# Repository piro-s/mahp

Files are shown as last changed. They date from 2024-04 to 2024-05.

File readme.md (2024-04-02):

# Music mini-amplifier with indicator:  
A simple two-channel amplifier on a chip TDA2822 with indicator.  

### Schemes:  
###### Amplifier_v0.1:  
[pdf](amplifier/docs/mahp_v0.1.pdf)  
###### Indicator_v0.1:  
[pdf](indicator/docs/indicator_v0.1.pdf)  

### Images:  
###### Amplifier_v0.1:  
top:  
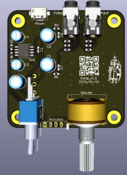
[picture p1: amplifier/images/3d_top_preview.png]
mahp_top_v0.1
  
bottom:  
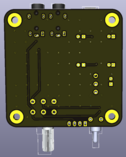
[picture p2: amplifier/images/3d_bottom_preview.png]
mahp_bottom_v0.1
  

###### Indicator_v0.1:  
top:  
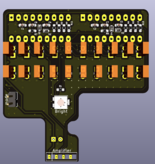
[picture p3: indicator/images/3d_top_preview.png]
indicator_top_v0.1
  
bottom:  
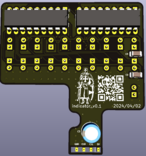
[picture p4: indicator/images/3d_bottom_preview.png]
indicator_bottom_v0.1
  

###### gerber:  
Archive for production:  
[Amplifier_v0.1](https://github.com/piro-s/mahp/raw/master/amplifier/gerber/mahp_v0.1.zip)  
[Indicator_v0.1](https://github.com/piro-s/mahp/raw/master/indicator/gerber/indicator_v0.1.zip)

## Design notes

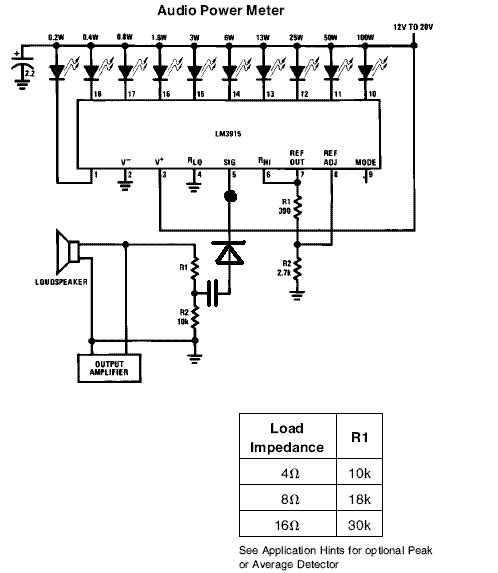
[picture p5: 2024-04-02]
indicator/datashits/lm3915.GIF

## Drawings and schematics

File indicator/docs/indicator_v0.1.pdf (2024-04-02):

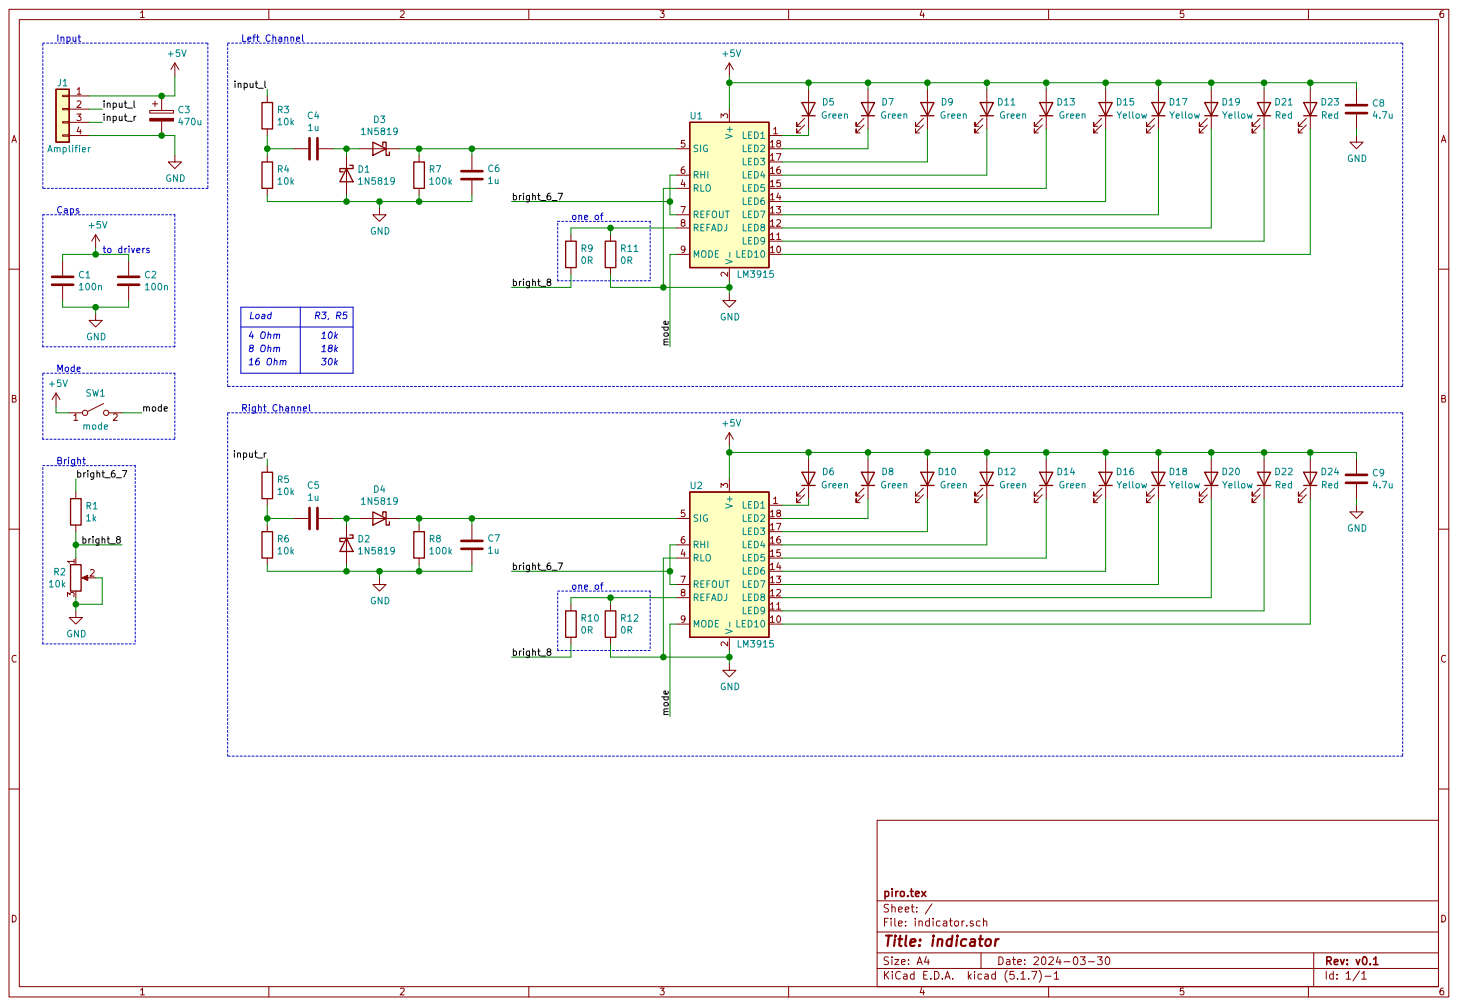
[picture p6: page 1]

3 RLO 4 SIG 5 RHI 6 REFOUT 7 REFADJ 8 MODE 9 U1

bright_6_7
one of

8 Ohm

3 RLO 4 SIG 5 RHI 6 REFOUT 7 REFADJ 8 MODE 9 U2

Id: 1/1 Title: indicator File: indicator.sch Sheet: / piro.tex

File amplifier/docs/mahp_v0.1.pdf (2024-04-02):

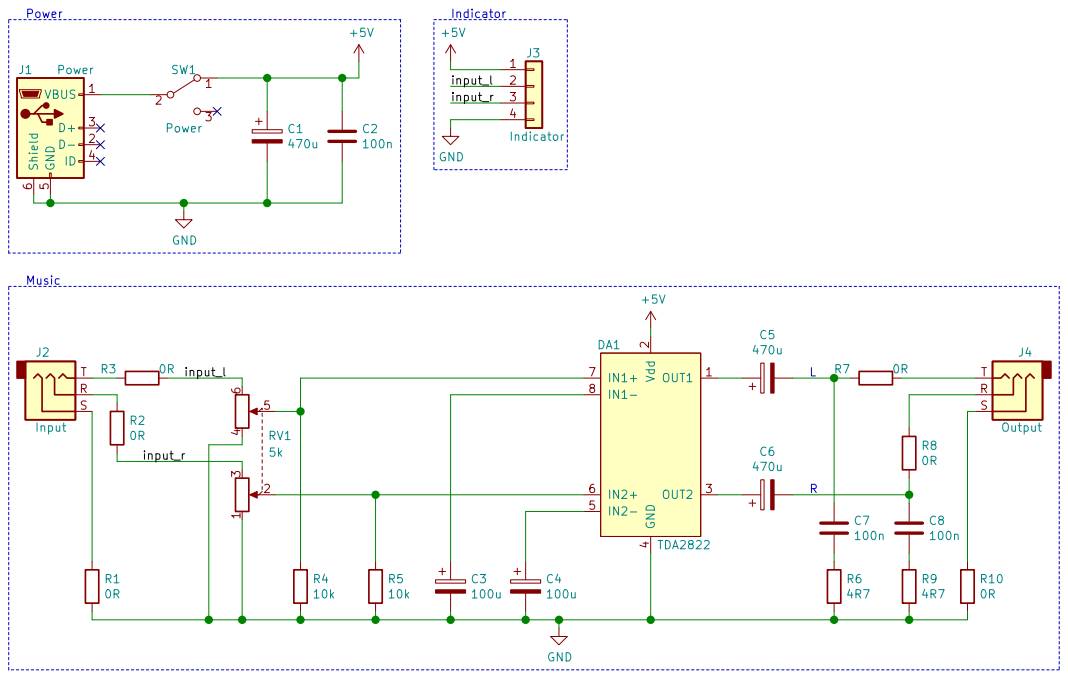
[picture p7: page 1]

File: music_amplifier_headphones.sch Sheet: / piro.tex

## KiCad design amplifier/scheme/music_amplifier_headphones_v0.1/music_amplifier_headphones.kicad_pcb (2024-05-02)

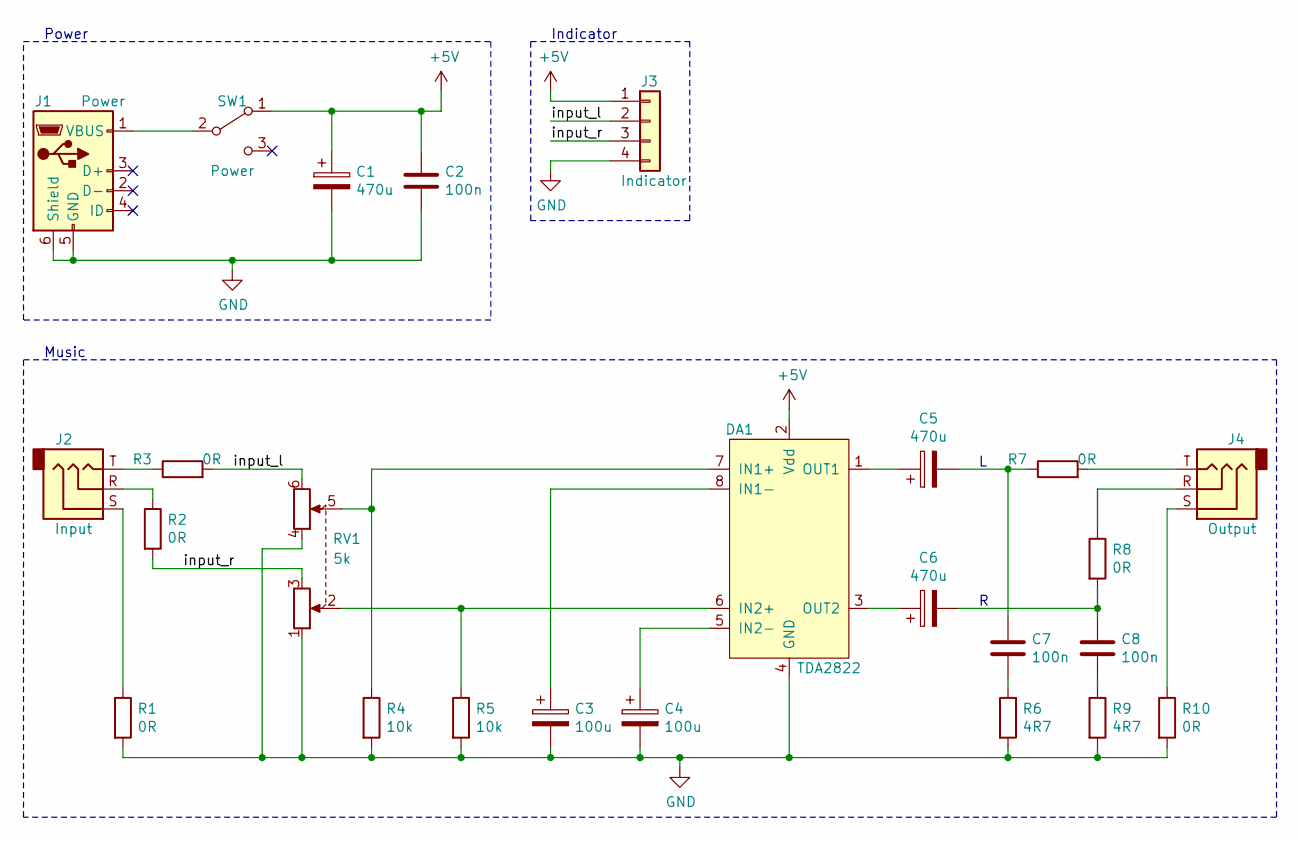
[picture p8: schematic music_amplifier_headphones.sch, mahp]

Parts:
C1, C5, C6: 470u; CP_Radial_D6.3mm_P2.50mm
C2, C7, C8: 100n; C_0603_1608Metric_Pad1.08x0.95mm_HandSolder
C3, C4: 100u; CP_Radial_D5.0mm_P2.00mm
DA1: TDA2822; SO-8_5.3x6.2mm_P1.27mm
J1: Power; USB_Micro-B_Amphenol_10104110_Horizontal
J2: Input; Jack_3.5mm_PJ322
J3: Indicator; Indicator_LM3915_female
J4: Output; Jack_3.5mm_PJ322
R1, R2, R3, R7, R8, R10: 0R; R_0603_1608Metric_Pad0.98x0.95mm_HandSolder
R4, R5: 10k; R_0603_1608Metric_Pad0.98x0.95mm_HandSolder
R6, R9: 4R7; R_0603_1608Metric_Pad0.98x0.95mm_HandSolder
RV1: 5k; Potentiometer_Alps_RK163_Dual_Horizontal
SW1: Power; MTS-102-C4

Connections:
+5V: C1.1, C2.1, DA1.2 (Vdd), J3.1, SW1.1 (A)
/input_l: J3.2, R3.2, RV1.6
/input_r: J3.3, R2.2, RV1.3
GND: C1.2, C2.2, C3.2, C4.2, DA1.4 (GND), J1.5 (GND), J1.6 (Shield), J3.4, R1.2, R4.2, R5.2, R6.2, R9.2, R10.2, RV1.1, RV1.4
unnamed: C3.1, DA1.8 (IN1-)
unnamed: C4.1, DA1.5 (IN2-)
unnamed: C5.1, DA1.1 (OUT1)
unnamed: C5.2, C7.1, R7.1
unnamed: C6.1, DA1.3 (OUT2)
unnamed: C6.2, C8.1, R8.2
unnamed: C7.2, R6.1
unnamed: C8.2, R9.1
unnamed: DA1.6 (IN2+), R5.1, RV1.2
unnamed: DA1.7 (IN1+), R4.1, RV1.5
unnamed: J1.1 (VBUS), SW1.2 (B)
unnamed: J2.R, R2.1
unnamed: J2.S, R1.1
unnamed: J2.T, R3.1
unnamed: J4.R, R8.1
unnamed: J4.S, R10.1
unnamed: J4.T, R7.2

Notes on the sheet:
Music
Power
Indicator

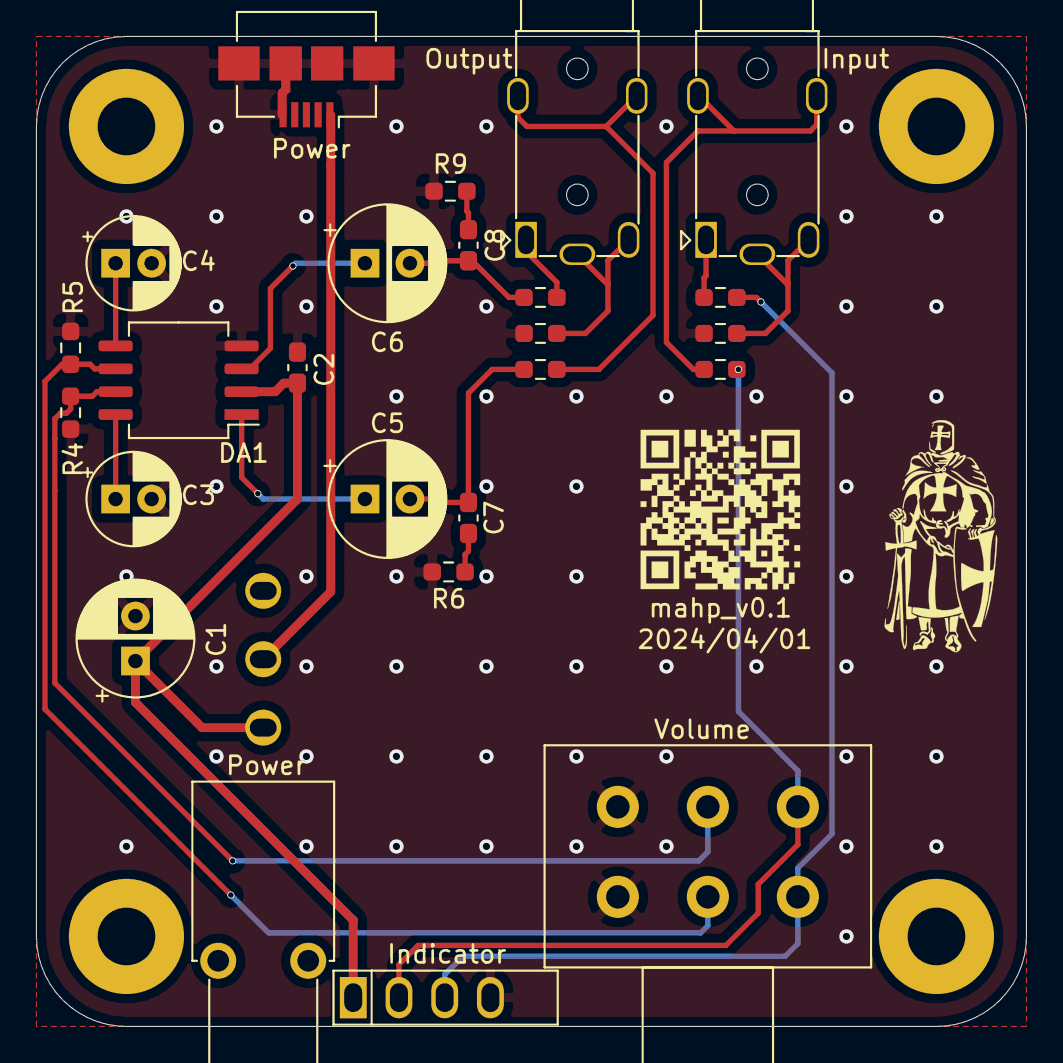
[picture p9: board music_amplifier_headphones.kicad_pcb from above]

Board: 2 copper layers, 55.0 x 55.0 mm, 25 parts (0 on the bottom side), 21 nets.

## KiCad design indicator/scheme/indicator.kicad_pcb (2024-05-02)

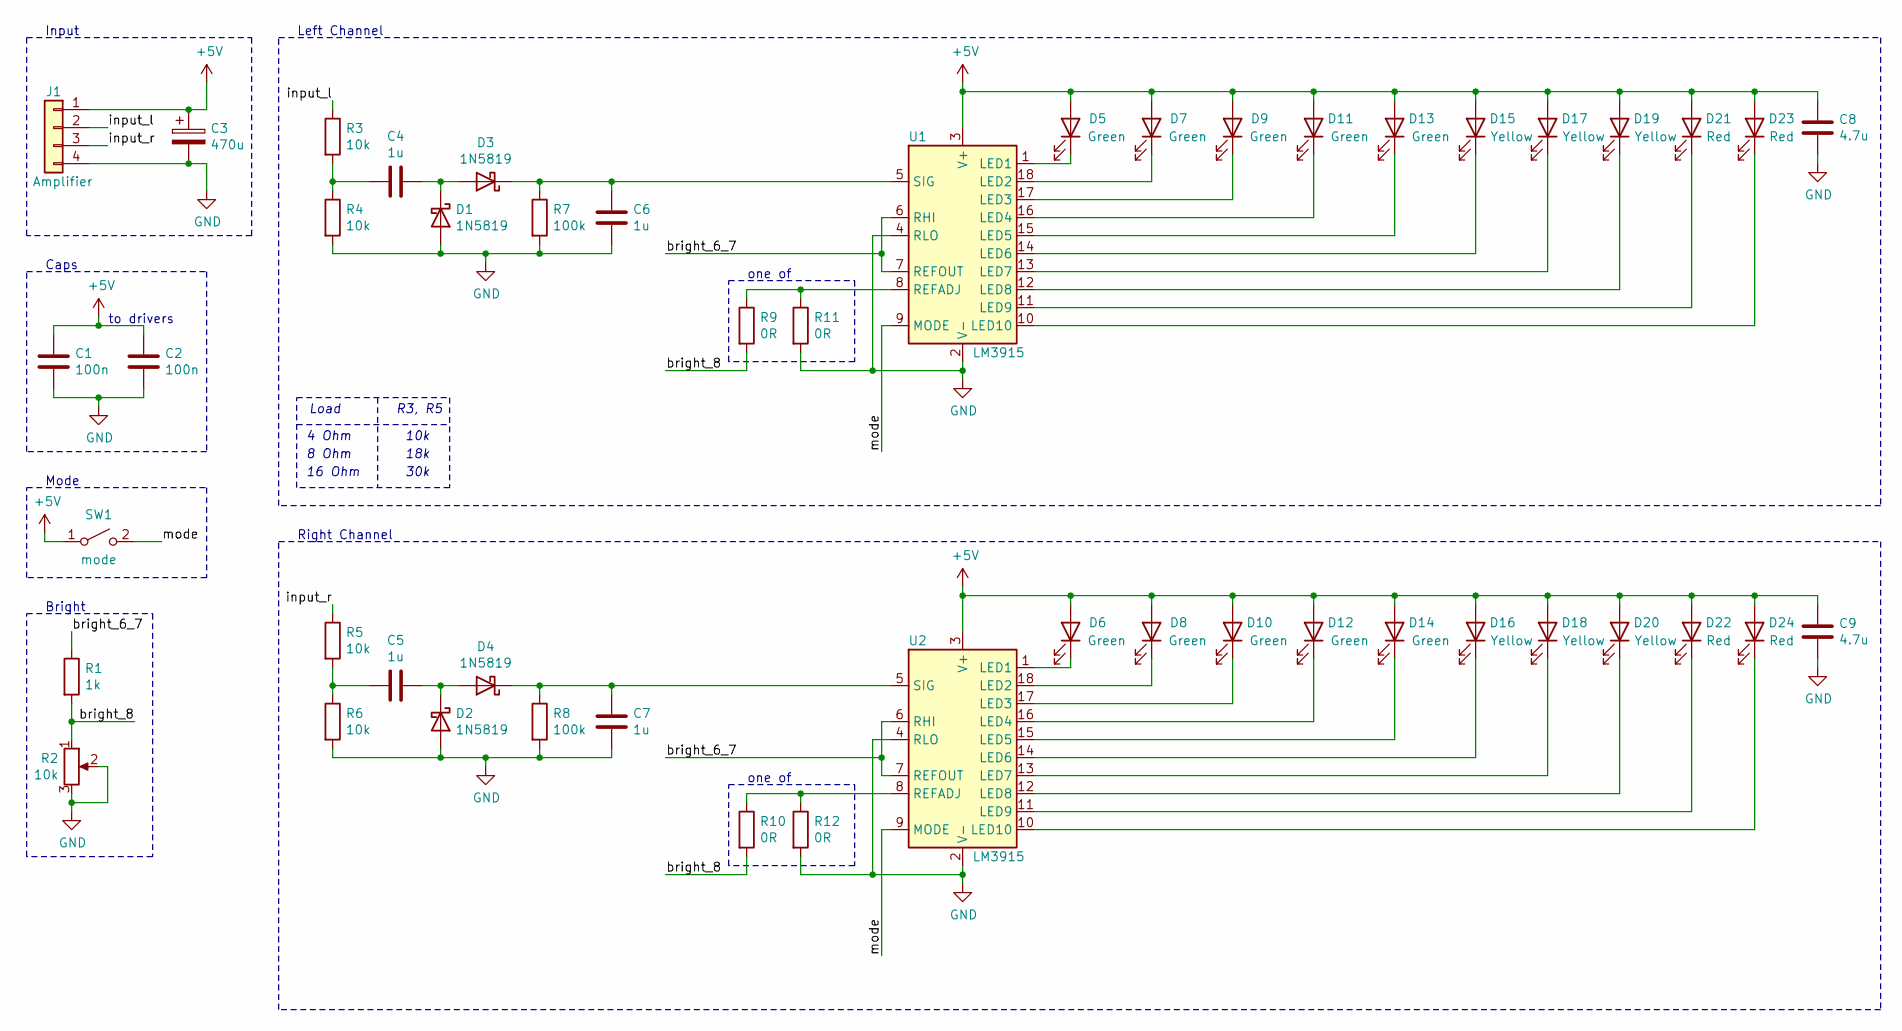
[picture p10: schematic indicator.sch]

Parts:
C1, C2: 100n; C_0603_1608Metric_Pad1.08x0.95mm_HandSolder
C3: 470u; CP_Radial_D6.3mm_P2.50mm
C4, C5, C6, C7: 1u; C_0603_1608Metric_Pad1.08x0.95mm_HandSolder
C8, C9: 4.7u; C_1206_3216Metric_Pad1.33x1.80mm_HandSolder
D1, D2, D3, D4: 1N5819; D_SOD-523
D5, D6, D7, D8, D9, D10, D11, D12, D13, D14: Green; LED_Rectangular_W3.9mm_H1.9mm
D15, D16, D17, D18, D19, D20: Yellow; LED_Rectangular_W3.9mm_H1.9mm
D21, D22, D23, D24: Red; LED_Rectangular_W3.9mm_H1.9mm
J1: Amplifier; Indicator_LM3915_male
R1: 1k; R_0603_1608Metric_Pad0.98x0.95mm_HandSolder
R2: 10k; Potentiometer_Bourns_3314J_Vertical
R3, R4, R5, R6: 10k; R_0603_1608Metric_Pad0.98x0.95mm_HandSolder
R7, R8: 100k; R_0603_1608Metric_Pad0.98x0.95mm_HandSolder
R9, R10, R11, R12: 0R; R_0603_1608Metric_Pad0.98x0.95mm_HandSolder
SW1: mode; PinHeader_1x02_P2.54mm_Vertical
U1, U2: LM3915; DIP-18_W7.62mm_LongPads

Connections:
+5V: C1.1, C2.1, C3.1, C8.1, C9.1, D5.2 (A), D6.2 (A), D7.2 (A), D8.2 (A), D9.2 (A), D10.2 (A), D11.2 (A), D12.2 (A), D13.2 (A), D14.2 (A), D15.2 (A), D16.2 (A), D17.2 (A), D18.2 (A), D19.2 (A), D20.2 (A), D21.2 (A), D22.2 (A), D23.2 (A), D24.2 (A), J1.1, SW1.1 (A), U1.3 (V+), U2.3 (V+)
/bright_6_7: R1.1, U1.6 (RHI), U1.7 (REFOUT), U2.6 (RHI), U2.7 (REFOUT)
/bright_8: R1.2, R2.1, R9.2, R10.2
/input_l: J1.2, R3.1
/input_r: J1.3, R5.1
/mode: SW1.2 (B), U1.9 (MODE), U2.9 (MODE)
GND: C1.2, C2.2, C3.2, C6.1, C7.1, C8.2, C9.2, D1.2 (A), D2.2 (A), J1.4, R2.2, R2.3, R4.2, R6.2, R7.2, R8.2, R11.2, R12.2, U1.2 (V-), U1.4 (RLO), U2.2 (V-), U2.4 (RLO)
unnamed: C4.1, D1.1 (K), D3.2 (A)
unnamed: C4.2, R3.2, R4.1
unnamed: C5.1, D2.1 (K), D4.2 (A)
unnamed: C5.2, R5.2, R6.1
unnamed: C6.2, D3.1 (K), R7.1, U1.5 (SIG)
unnamed: C7.2, D4.1 (K), R8.1, U2.5 (SIG)
unnamed: D5.1 (K), U1.1 (LED1)
unnamed: D6.1 (K), U2.1 (LED1)
unnamed: D7.1 (K), U1.18 (LED2)
unnamed: D8.1 (K), U2.18 (LED2)
unnamed: D9.1 (K), U1.17 (LED3)
unnamed: D10.1 (K), U2.17 (LED3)
unnamed: D11.1 (K), U1.16 (LED4)
unnamed: D12.1 (K), U2.16 (LED4)
unnamed: D13.1 (K), U1.15 (LED5)
unnamed: D14.1 (K), U2.15 (LED5)
unnamed: D15.1 (K), U1.14 (LED6)
unnamed: D16.1 (K), U2.14 (LED6)
unnamed: D17.1 (K), U1.13 (LED7)
unnamed: D18.1 (K), U2.13 (LED7)
unnamed: D19.1 (K), U1.12 (LED8)
unnamed: D20.1 (K), U2.12 (LED8)
unnamed: D21.1 (K), U1.11 (LED9)
unnamed: D22.1 (K), U2.11 (LED9)
unnamed: D23.1 (K), U1.10 (LED10)
unnamed: D24.1 (K), U2.10 (LED10)
unnamed: R10.1, R12.1, U2.8 (REFADJ)
unnamed: R9.1, R11.1, U1.8 (REFADJ)

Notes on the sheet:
Input
Caps
to drivers
one of
Left Channel
Right Channel
Mode
Bright
Load
R3, R5
4 Ohm
8 Ohm
16 Ohm
10k
18k
30k

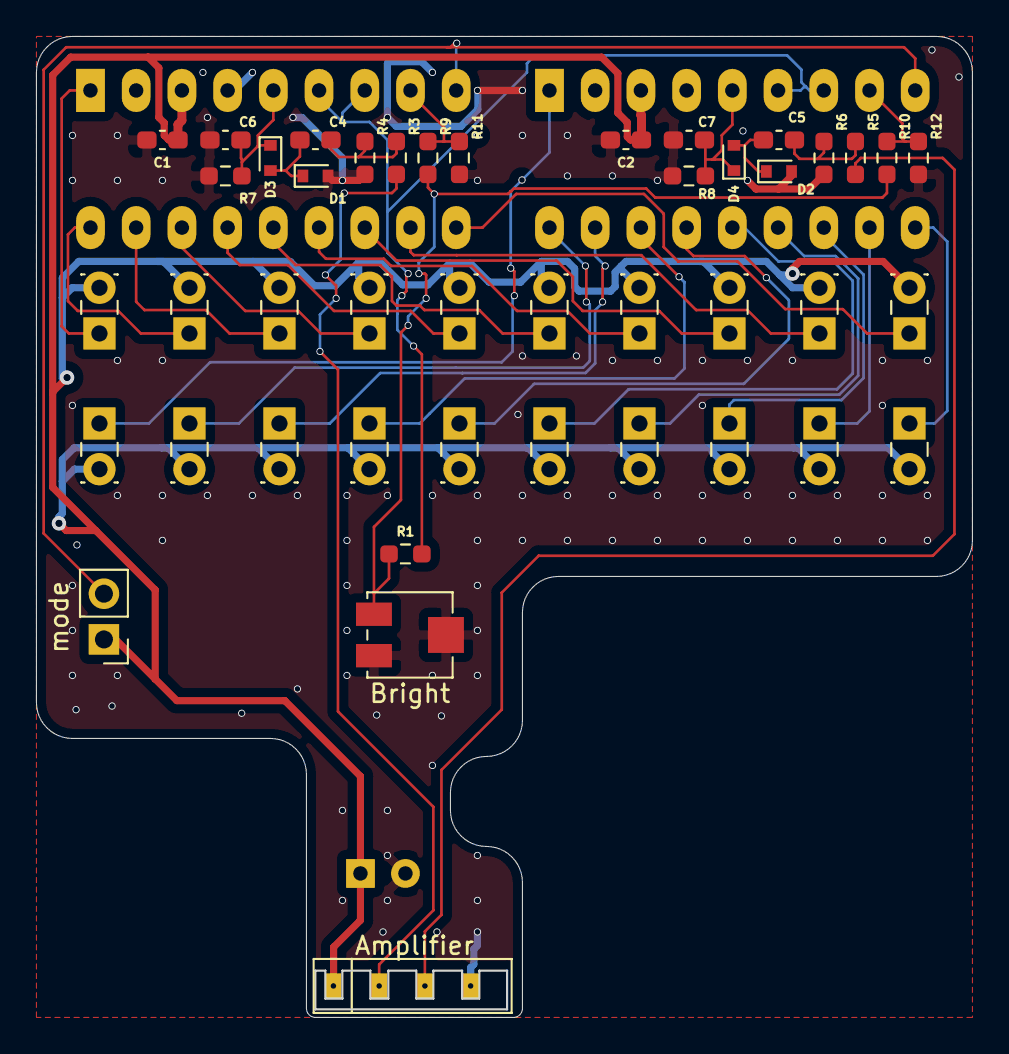
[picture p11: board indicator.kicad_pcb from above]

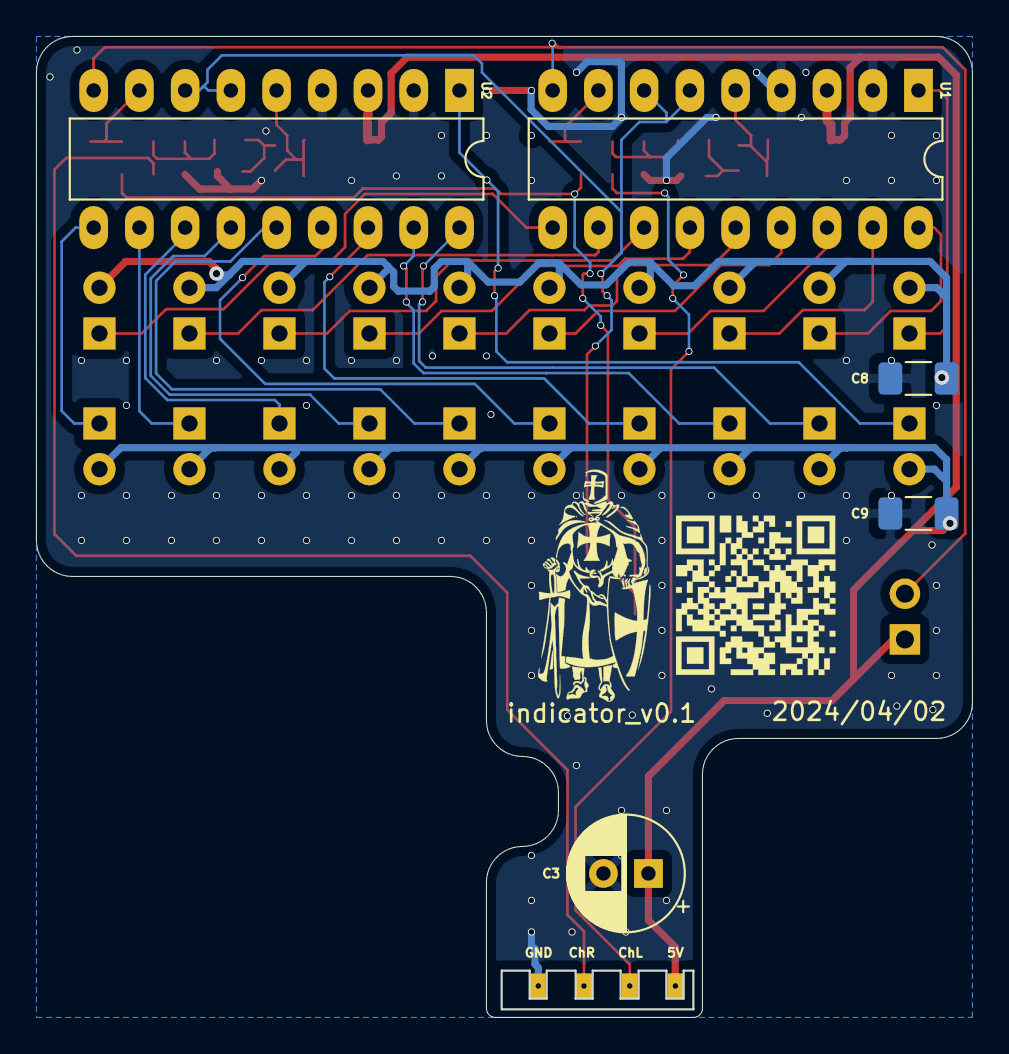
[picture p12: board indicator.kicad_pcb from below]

Board: 2 copper layers, 52.0 x 54.5 mm, 49 parts (5 on the bottom side), 35 nets.

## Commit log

2024-04-02 small: Gerber links
    Fix gerber links in readme.
2024-05-02 small: QR code
    Change QR code from github to site.
    [indicator.kicad_pcb, music_amplifier_headphones.kicad_pcb]
